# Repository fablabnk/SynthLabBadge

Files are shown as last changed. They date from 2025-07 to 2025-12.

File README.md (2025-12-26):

A light-to-sound badge-synth based on Dylan B's open-hardware Beam Catcher project and coming out of our weekly SynthLab audio hardware meetups at fablab|nk. The badge is designed to be a first-intro to DIY synthesiser building for new visitors. 

Check the [PDF build guide](./BuildGuide/SynthLabBadgeBuildGuide.pdf).

<a href="./BuildGuide/SynthLabBadgeBuildGuide.pdf">
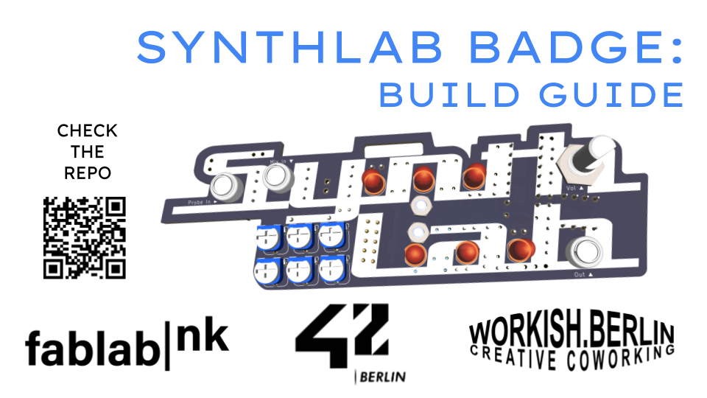
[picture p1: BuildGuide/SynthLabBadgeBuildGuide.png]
    
</a>

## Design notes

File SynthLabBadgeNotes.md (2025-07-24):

SynthLab "Beam Catcher" Badge

# Mouse bites

Graphic import scale: 0.540000

- Badge mounts in panel and can be snapped out
- Traces can't be routed through mouse bites so Eurorack connector must live on badge
- 

1.78

105.156-1.78

# BOM

Thonkiconn input 1 (mix input - will this work?)
Thonkiconn input 2 (sensor)
Thonkiconn output 2 (mono or stereo?)
Master volume pot
6 LEDs
6 trimpots
2 photodiodes
Dual 9v/12v operation (battery, positive rail)
9V battery clip
10 pin IDC connector
Bridgeable reverse voltage protection

# Dimensions
Badge 100 tall
Panel 128.5 tall, 8HP wide 40.64 (or 10HP 50.80)
with screw slots, module name 
 
Logo inside at angle, with mousebites, credits on back

Pot and jack sockets to mount to PCB/Panel and be wired point to point - in which case use guitar pot

Laser cut panel to contain battery and pot (only when used as badge)
- how to mount to PCB - nylon mounts, screws, simpler?
Battery thickness: 17.5 mm
Thonkiconn (base plus pins): 12.5
Pot: don't have datasheet, but must be similar to thonkiconn

How to ensure Eurorack level output? Adjust inverting input and in-the-loop resistor values

height 36mm
wide 100mm
2mm depth fro text and 2mm depth for base badge

clip hole
3mm from top of center

4mm height and 16mm length

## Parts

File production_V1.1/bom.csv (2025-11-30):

Designator | Footprint | Quantity | Value | LCSC Part #
_2, |  | 2
BATTERYMOUNT | 9VBatteryClop | 1 | 9VBatteryClop
BT1 | PinHeader_1x02_P2.54mm_Vertical | 1 | 9V Battery
C1 | C_Axial_L3.8mm_D2.6mm_P7.50mm_Horizontal | 1 | 1uF
C10, C2, C3, C4, C5, C6, C7, C8, C9 | C_Axial_L3.8mm_D2.6mm_P7.50mm_Horizontal | 9 | 100nF
C11 | CP_Radial_D5.0mm_P2.50mm | 1 | 22uF
D2, D3, D4, D5, D6, D7 | LED_D5.0mm | 6 | LED
D8 | D_DO-41_SOD81_P10.16mm_Horizontal | 1 | 5817
J2_2 | Faceplate_Hole_Jack_3.5mm_NoPadNumber | 1 | Probe In
J2 | EighthInch_PJ398SM_Silkscreen_Courtyard_Only | 1 | Probe In
J3_2 | Faceplate_Hole_Jack_3.5mm_NoPadNumber | 1 | Mix_In
J3 | EighthInch_PJ398SM_Silkscreen_Courtyard_Only | 1 | Mix In
J4_2 | EighthInch_PJ398SM_Silkscreen_Courtyard_Only | 1 | Out
J4 | Faceplate_Hole_Jack_3.5mm_NoPadNumber | 1 | Out
J5 | IDC-Header_2x05_P2.54mm_Vertical_Euro_Power_Striped_ThickerText | 1 | Eurorack_Power_10pin_Unshrouded
J6 | PinHeader_1x02_P2.54mm_Vertical | 1 | Mix In
J7 | PinHeader_1x02_P2.54mm_Vertical | 1 | Probe In
J8 | PinHeader_1x03_P2.54mm_Vertical | 1 | Out
J9 | PinHeader_1x02_P2.54mm_Vertical | 1 | Vol Pot
MOUSE-BITE-1MM-SLOT_10, MOUSE-BITE-1MM-SLOT_9, MOUSE-BITE-1MM-SLOT_8, MOUSE-BITE-1MM-SLOT_7, MOUSE-BITE-1MM-SLOT_6, MOUSE-BITE-1MM-SLOT_5, MOUSE-BITE-1MM-SLOT_4, MOUSE-BITE-1MM-SLOT_3, MOUSE-BITE-1MM-SLOT_2, MOUSE-BITE-1MM-SLOT | mouse-bite-1mm-slot | 10 | VAL**
R1, R10, R12, R13, R14, R15, R16, R17, R18, R19, R2, R5, R6, R7, R8, R9 | R_Axial_DIN0207_L6.3mm_D2.5mm_P2.54mm_Vertical | 16 | 1k
R11 | R_Axial_DIN0207_L6.3mm_D2.5mm_P2.54mm_Vertical | 1 | 470
R20, R3 | R_Axial_DIN0207_L6.3mm_D2.5mm_P2.54mm_Vertical | 2 | 100K
R4 | R_Axial_DIN0207_L6.3mm_D2.5mm_P2.54mm_Vertical | 1 | 10k
RV1, RV2, RV4, RV5, RV6, RV7 | Potentiometer_Runtron_RM-065_Vertical | 6 | 1M
RV3_2 | Pot_9mm_DShaft_Silkscreen_Courtyard_Only | 1 | 100K
RV3 | Faceplate_Hole_Jack_3.5mm_NoPadNumber | 1 | 100K
U1 | DIP-8_W7.62mm | 1 | LM358
U2 | DIP-14_W7.62mm | 1 | CD40106BPWR

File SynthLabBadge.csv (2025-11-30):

Reference | Qty | Value | DNP | Exclude from BOM | Exclude from Board | Footprint | Display
BT1 | 1 | 9V Battery |  |  |  | Connector_PinHeader_2.54mm:PinHeader_1x02_P2.54mm_Vertical
C1 | 1 | 1uF |  |  |  | Capacitor_THT:C_Axial_L3.8mm_D2.6mm_P7.50mm_Horizontal
C2,C3,C4,C5,C6,C7,C8,C9,C10 | 9 | 100nF |  |  |  | Capacitor_THT:C_Axial_L3.8mm_D2.6mm_P7.50mm_Horizontal
C11 | 1 | 22uF |  |  |  | Capacitor_THT:CP_Radial_D5.0mm_P2.50mm
D2,D3,D4,D5,D6,D7 | 6 | LED |  |  |  | LED_THT:LED_D5.0mm
D8 | 1 | 5817 |  |  |  | Diode_THT:D_DO-41_SOD81_P10.16mm_Horizontal
J2 | 1 | Probe In |  |  |  | Library:EighthInch_PJ398SM_Silkscreen_Courtyard_Only
J3 | 1 | Mix In |  |  |  | Library:EighthInch_PJ398SM_Silkscreen_Courtyard_Only
J4 | 1 | Out |  |  |  | Library:EighthInch_PJ398SM_Silkscreen_Courtyard_Only
J5 | 1 | Eurorack_Power_10pin_Unshrouded |  |  |  | Library:IDC-Header_2x05_P2.54mm_Vertical_Euro_Power_Striped_ThickerText
J6 | 1 | Mix In |  |  |  | Connector_PinHeader_2.54mm:PinHeader_1x02_P2.54mm_Vertical
J7 | 1 | Probe In |  |  |  | Connector_PinHeader_2.54mm:PinHeader_1x02_P2.54mm_Vertical
J8 | 1 | Out |  |  |  | Connector_PinHeader_2.54mm:PinHeader_1x03_P2.54mm_Vertical
J9 | 1 | Vol Pot |  |  |  | Connector_PinHeader_2.54mm:PinHeader_1x02_P2.54mm_Vertical
R1,R2,R5,R7,R8,R9,R10,R12,R13,R14,R15,R16,R17,R18,R19 | 15 | 1k |  |  |  | Resistor_THT:R_Axial_DIN0207_L6.3mm_D2.5mm_P2.54mm_Vertical
R3,R20 | 2 | 100k |  |  |  | Resistor_THT:R_Axial_DIN0207_L6.3mm_D2.5mm_P2.54mm_Vertical
R4 | 1 | 10k |  |  |  | Resistor_THT:R_Axial_DIN0207_L6.3mm_D2.5mm_P2.54mm_Vertical
R6 | 1 | 1.5k |  |  |  | Resistor_THT:R_Axial_DIN0207_L6.3mm_D2.5mm_P2.54mm_Vertical
R11 | 1 | 470 |  |  |  | Resistor_THT:R_Axial_DIN0207_L6.3mm_D2.5mm_P2.54mm_Vertical
RV1,RV2,RV4,RV5,RV6,RV7 | 6 | 1M |  |  |  | Potentiometer_THT:Potentiometer_Runtron_RM-065_Vertical
RV3 | 1 | 100K |  |  |  | Library:Pot_9mm_DShaft_Silkscreen_Courtyard_Only
U1 | 1 | LM358 |  |  |  | Package_DIP:DIP-8_W7.62mm
U2 | 1 | CD40106BPWR |  |  |  | Package_DIP:DIP-14_W7.62mm | 40106
D1 | 1 | D_Photo | DNP |  | Excluded from board
J1 | 1 | Probe Out | DNP |  | Excluded from board

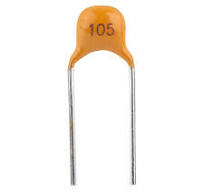
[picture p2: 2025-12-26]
BuildGuide/ComponentImages/download.jpeg

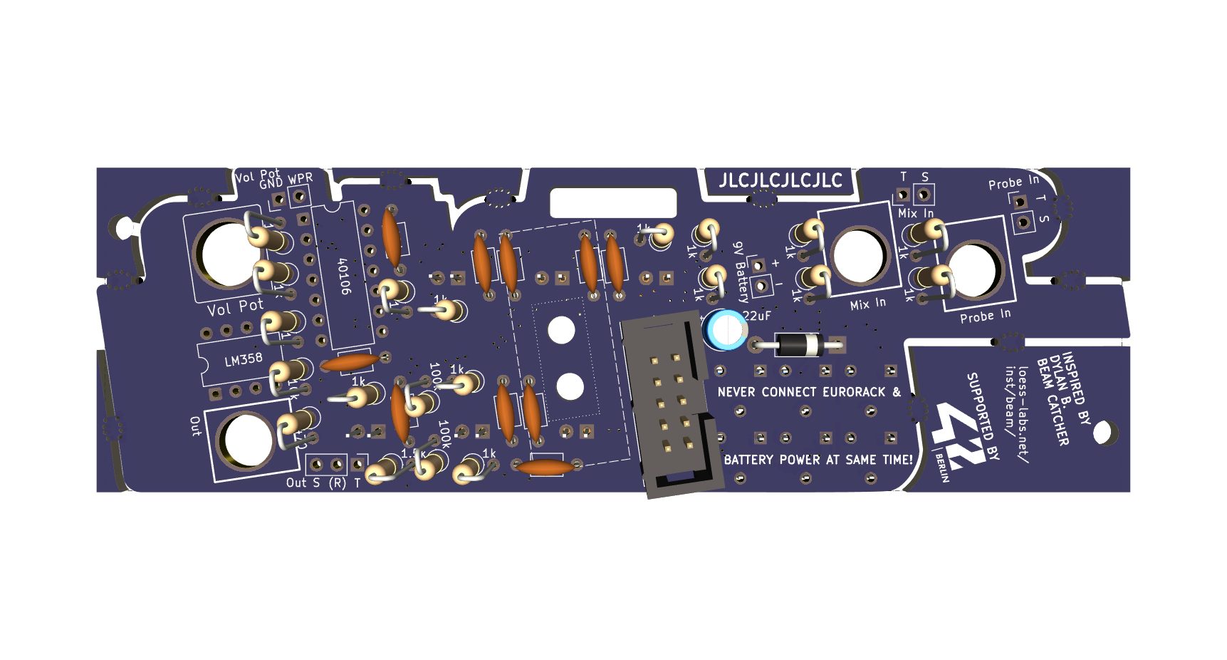
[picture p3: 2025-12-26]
BuildGuide/6-EurorackComponents.png

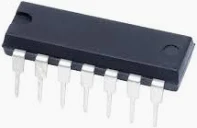
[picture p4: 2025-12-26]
BuildGuide/ComponentImages/CD40106.webp

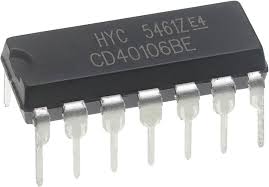
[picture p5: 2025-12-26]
BuildGuide/ComponentImages/CD40106.jpeg

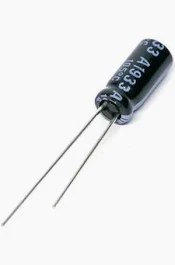
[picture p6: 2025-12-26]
BuildGuide/ComponentImages/shopping.webp

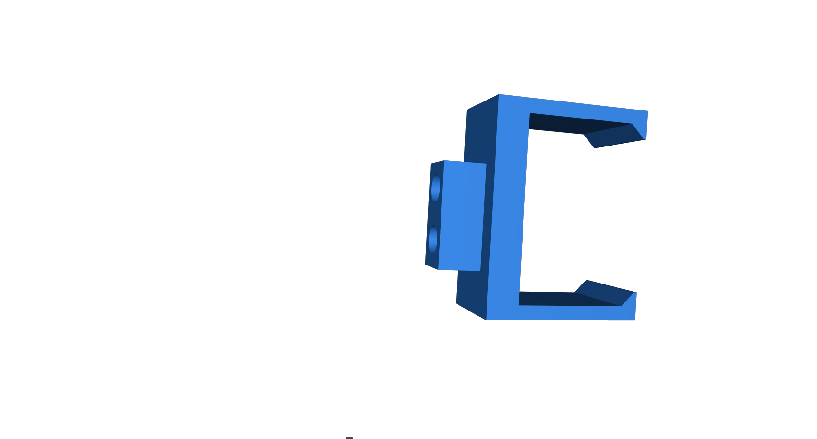
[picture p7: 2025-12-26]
BuildGuide/ComponentImages/9VBatteryMount.png

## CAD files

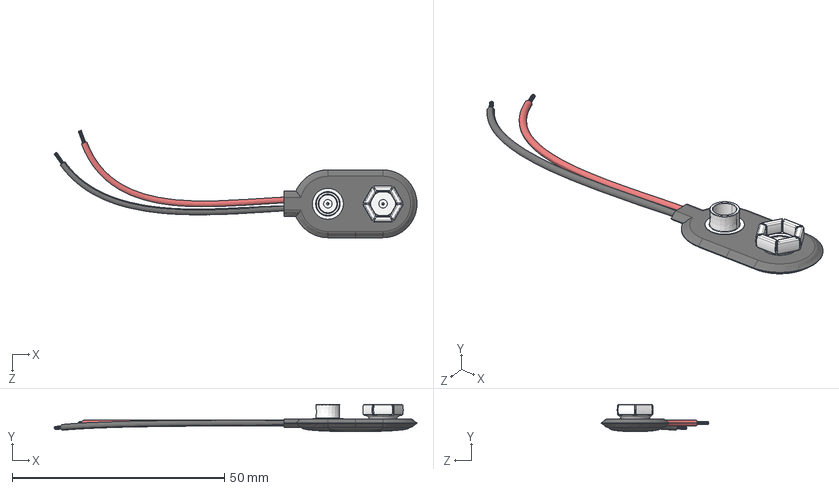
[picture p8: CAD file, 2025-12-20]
3DModels/9V Battery Clip Connector.STEP
85.5 x 6.40 x 25.3 mm

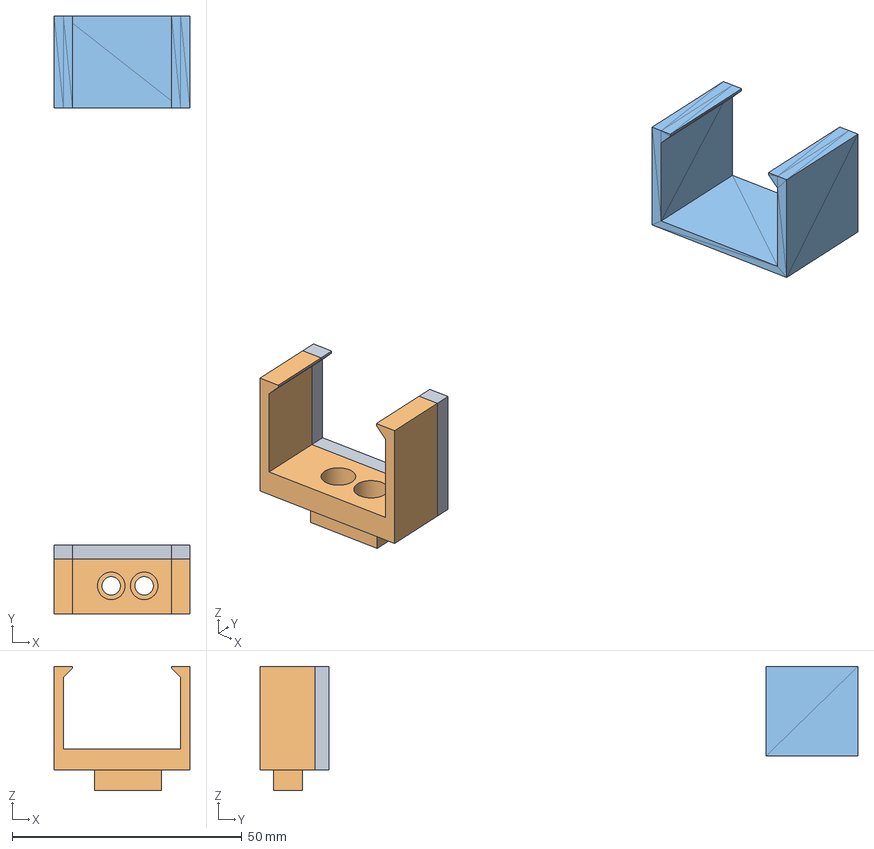
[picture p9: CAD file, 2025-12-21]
9VBatteryClipModel/9VBatteryClipModel.FCStd
29.5 x 130.0 x 27.0 mm
Slice.0
Slice.1
_9vClip_plain001

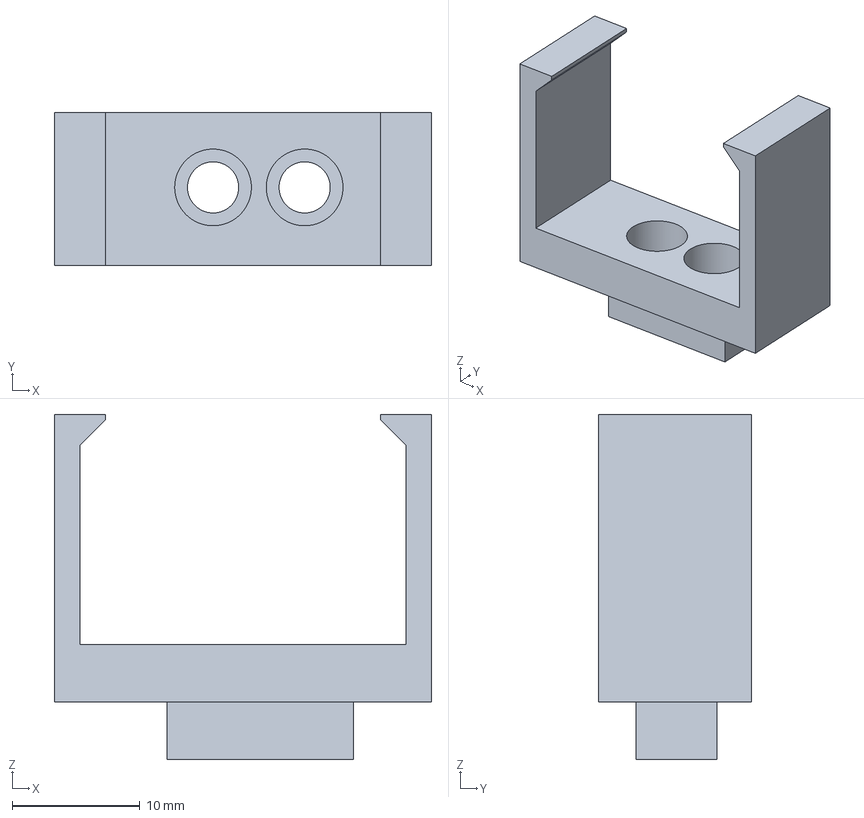
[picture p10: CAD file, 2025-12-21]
9VBatteryClipModel/9VBatteryClipModel-Slice.1.3mf
29.5 x 12.0 x 27.0 mm

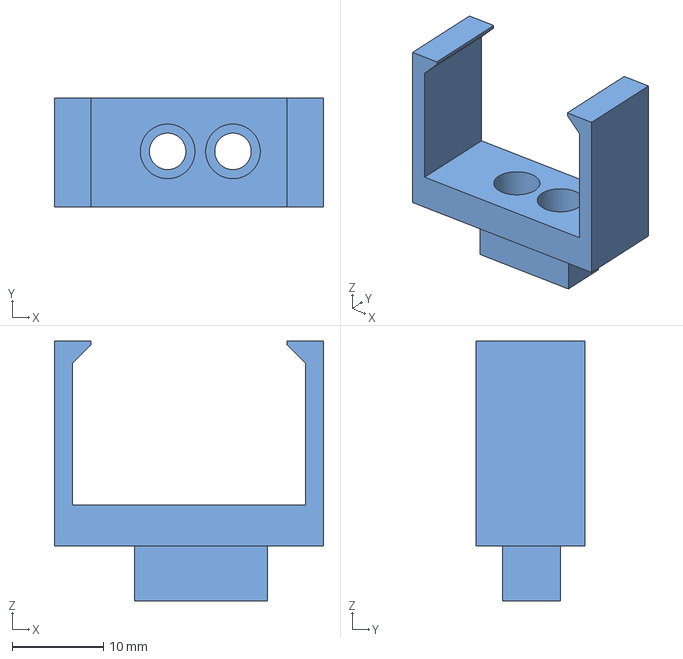
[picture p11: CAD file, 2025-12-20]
3DModels/9VBatteryClip-3DModel.step
29.5 x 12.0 x 28.5 mm

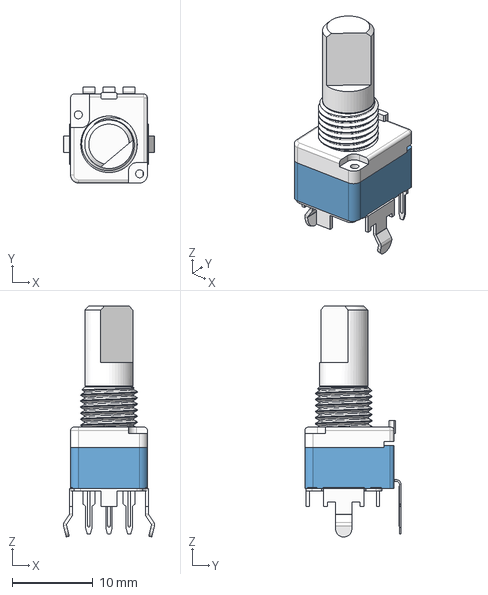
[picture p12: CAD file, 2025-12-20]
3DModels/POT-R-0904N-L-15F.step
11.3 x 11.9 x 28.6 mm

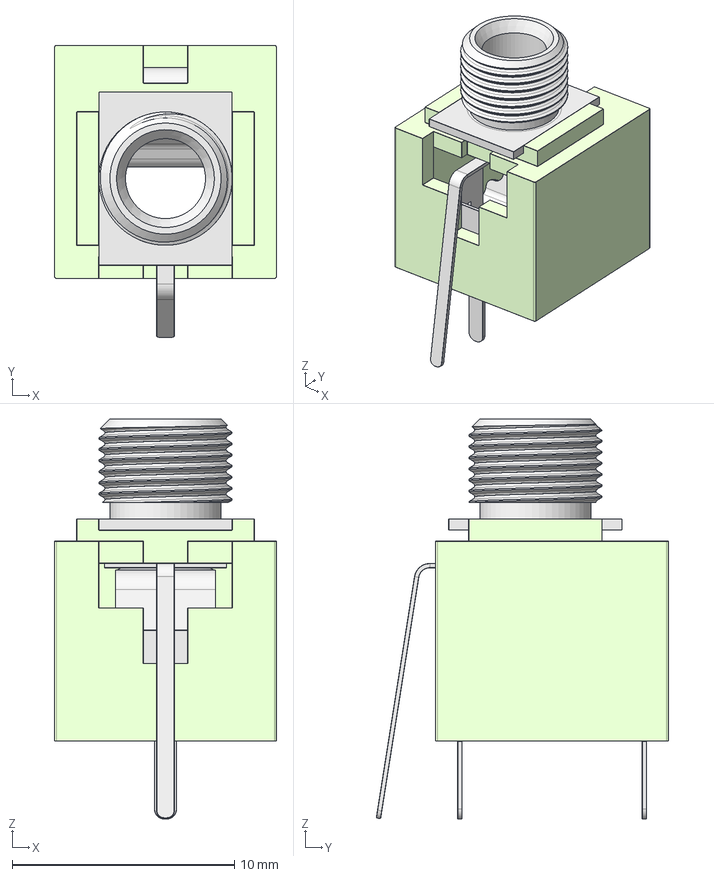
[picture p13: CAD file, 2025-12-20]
3DModels/WPQ-P419GR-Part.step
10.0 x 13.2 x 18.0 mm
Pin 3
Pin 2
Pin 1
Socket

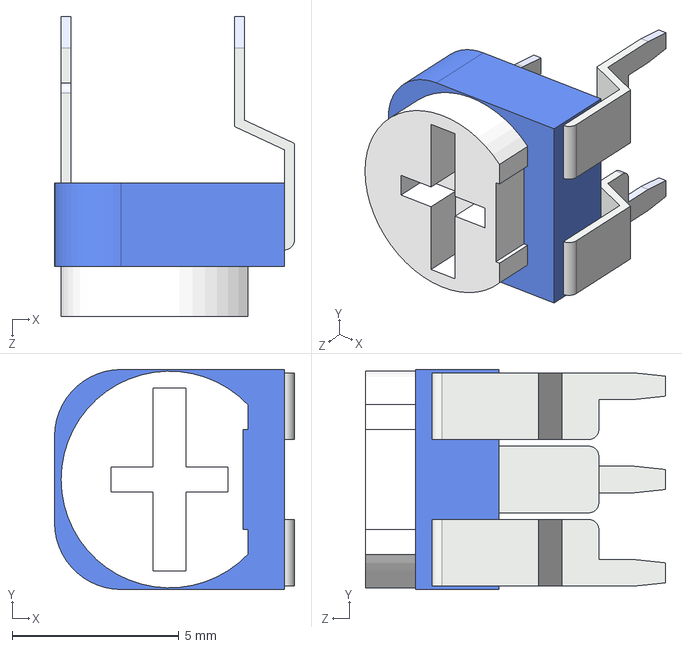
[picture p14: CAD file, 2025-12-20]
3DModels/Potentiometer Blue.STEP
7.20 x 6.60 x 9.00 mm

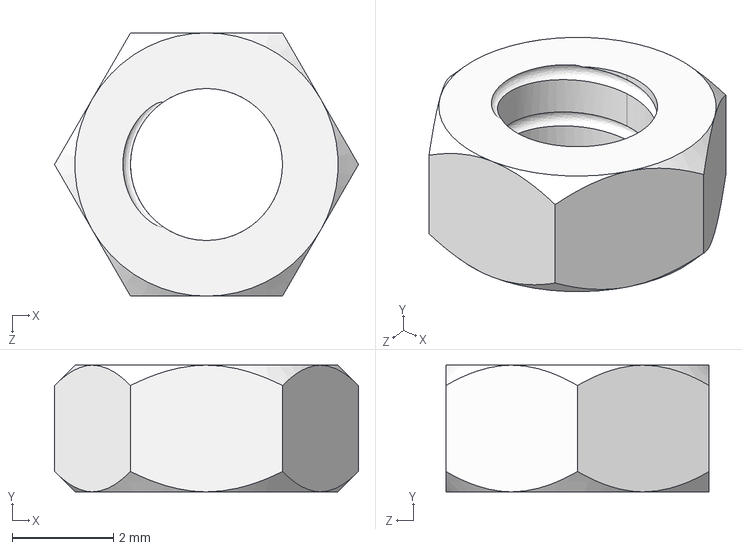
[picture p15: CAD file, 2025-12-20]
3DModels/M3 Nut.STEP
6.00 x 2.50 x 5.20 mm

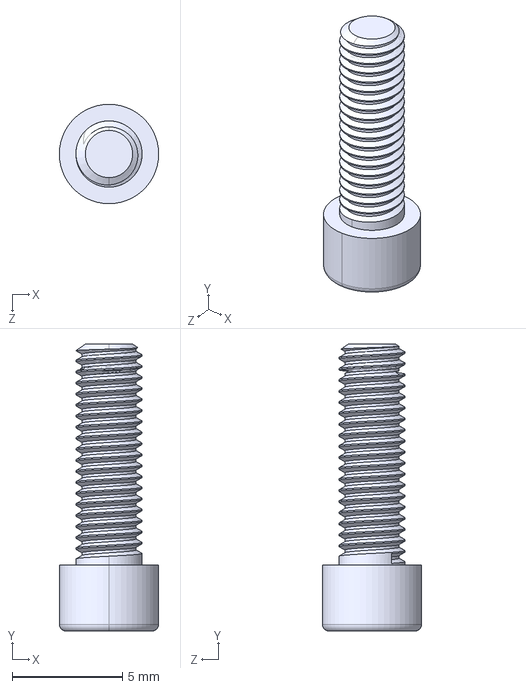
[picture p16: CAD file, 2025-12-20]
3DModels/M3x10.STEP
4.50 x 13.0 x 4.50 mm

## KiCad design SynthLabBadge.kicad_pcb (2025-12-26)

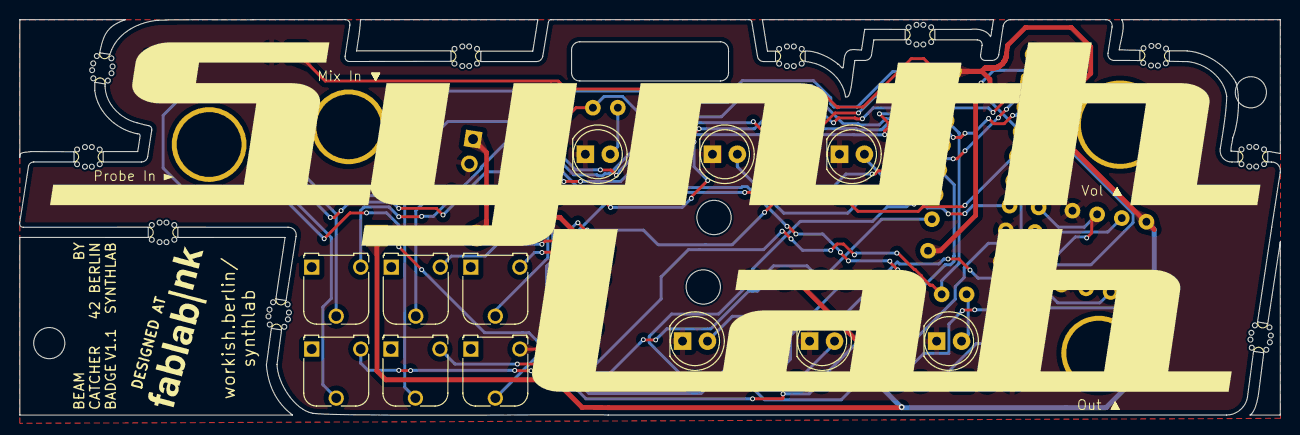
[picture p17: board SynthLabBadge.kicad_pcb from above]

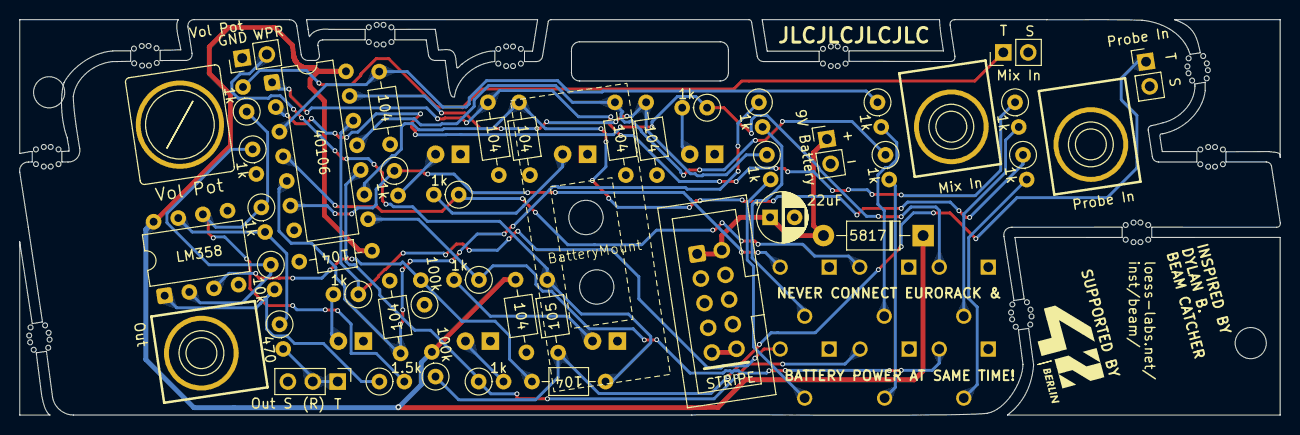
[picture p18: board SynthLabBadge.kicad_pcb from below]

Board: 2 copper layers, 128.5 x 40.3 mm, 71 parts (45 on the bottom side), 37 nets.

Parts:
BT1: 9V Battery; PinHeader_1x02_P2.54mm_Vertical
BatteryMount: 9VBatteryClop
C1: 1uF; C_Axial_L3.8mm_D2.6mm_P7.50mm_Horizontal_Disc3DModel
C2, C3, C4, C5, C6, C7, C8, C9, C10: 100nF; C_Axial_L3.8mm_D2.6mm_P7.50mm_Horizontal_Disc3DModel
C11: 22uF; CP_Radial_D5.0mm_P2.50mm
D2, D3, D4, D5, D6, D7: LED; LED_D5.0mm_Lowered
D8: 5817; D_DO-41_SOD81_P10.16mm_Horizontal
J2: Probe In; Faceplate_Hole_Jack_3.5mm_NoPadNumber
J2#2: Probe In; EighthInch_PJ398SM_Silkscreen_Courtyard_Only
J3: Mix_In; Faceplate_Hole_Jack_3.5mm_NoPadNumber
J3#2: Mix In; EighthInch_PJ398SM_Silkscreen_Courtyard_Only
J4: Out; Faceplate_Hole_Jack_3.5mm_NoPadNumber
J4#2: Out; EighthInch_PJ398SM_Silkscreen_Courtyard_Only
J5: Eurorack_Power_10pin_Unshrouded; IDC-Header_2x05_P2.54mm_Vertical_Euro_Power_Striped_Thicker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
J6: Mix In; PinHeader_1x02_P2.54mm_Vertical
J7: Probe In; PinHeader_1x02_P2.54mm_Vertical
J8: Out; PinHeader_1x03_P2.54mm_Vertical
J9: Vol Pot; PinHeader_1x02_P2.54mm_Vertical
R1, R2, R5, R7, R8, R9, R10, R12, R13, R14, R15, R16, R17, R18, R19: 1k; R_Axial_DIN0207_L6.3mm_D2.5mm_P2.54mm_Vertical
R3, R20: 100k; R_Axial_DIN0207_L6.3mm_D2.5mm_P2.54mm_Vertical
R4: 10k; R_Axial_DIN0207_L6.3mm_D2.5mm_P2.54mm_Vertical
R6: 1.5k; R_Axial_DIN0207_L6.3mm_D2.5mm_P2.54mm_Vertical
R11: 470; R_Axial_DIN0207_L6.3mm_D2.5mm_P2.54mm_Vertical
RV1, RV2, RV4, RV5, RV6, RV7: 1M; Potentiometer_Runtron_RM-065_Vertical_With3DModel
RV3: 100K; Faceplate_Hole_Jack_3.5mm_NoPadNumber
RV3#2: 100K; Pot_9mm_DShaft_Silkscreen_Courtyard_Only
U1: LM358; DIP-8_W7.62mm
U2: CD40106BPWR; DIP-14_W7.62mm
mouse-bite-1mm-slot, mouse-bite-1mm-slot#2, mouse-bite-1mm-slot#3, mouse-bite-1mm-slot#4, mouse-bite-1mm-slot#5, mouse-bite-1mm-slot#6, mouse-bite-1mm-slot#7, mouse-bite-1mm-slot#8, mouse-bite-1mm-slot#9, mouse-bite-1mm-slot#10: VAL**; mouse-bite-1mm-slot

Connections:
GND: BT1.2 (-), C3.2, C4.2, C5.2, C6.2, C7.2, C8.2, C9.2, C10.2, C11.2, D2.1 (K), D3.1 (K), D4.1 (K), D5.1 (K), D6.1 (K), D7.1 (K), J5.3 (GND), J5.4 (GND), J5.5 (GND), J5.6 (GND), J5.7 (GND), J5.8 (GND), J6.S (Pin_2), J7.S (Pin_2), J8.S (Pin_3), J9.1, R3.1, R5.2, U1.4 (V-), U1.5 (+), U2.7 (VSS)
unnamed: BT1.1 (+), C11.1, D8.2 (A), J5.1 (+12V), J5.2 (+12V)
unnamed: D2.2 (A), R14.2
unnamed: D3.2 (A), R17.2
unnamed: D4.2 (A), R15.2
unnamed: D5.2 (A), R18.2
unnamed: D6.2 (A), R16.2
unnamed: D7.2 (A), R19.2
unnamed: J5.9 (-12V), J5.10 (-12V)
unnamed: J6.T (Pin_1), R10.2
unnamed: C1.1, J7.T (Pin_1), R20.1
unnamed: J8.R (Pin_1), J8.T (Pin_2), R11.2
unnamed: C1.2, C2.1, J9.2
unnamed: R1.2, RV1.2
unnamed: R2.2, RV2.2
unnamed: R4.2, R6.1, U1.1
unnamed: R8.2, RV4.2
unnamed: R9.2, RV5.2
unnamed: R7.2, R11.1, U1.7
unnamed: R12.2, RV6.2
unnamed: R13.2, RV7.2
unnamed: C2.2, R3.2, U1.3 (+)
unnamed: R4.1, R5.1, U1.2 (-)
unnamed: R6.2, R7.1, R10.1, U1.6 (-)
unnamed: C4.1, R1.1, U2.1 (I)
unnamed: R14.1, RV1.3, U2.2 (O)
unnamed: C5.1, R2.1, U2.3 (I)
unnamed: R17.1, RV2.3, U2.4 (O)
unnamed: C6.1, R8.1, U2.5 (I)
unnamed: R15.1, RV4.3, U2.6 (O)
unnamed: C7.1, R9.1, U2.9 (I)
unnamed: R18.1, RV5.3, U2.8 (O)
unnamed: C8.1, R12.1, U2.11 (I)
unnamed: R16.1, RV6.3, U2.10 (O)
unnamed: C9.1, R13.1, U2.13 (I)
unnamed: R19.1, RV7.3, U2.12 (O)
VCC: C3.1, C10.1, D8.1 (K), R20.2, U1.8 (V+), U2.14 (VDD)

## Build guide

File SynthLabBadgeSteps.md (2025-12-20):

# Noticed that:

- check if we have enough 1.5k resistors (or other values)
	- in case where output of 9V badge runs into 12V badge, we need more boost
- decide on 1 colour or two (probably 1 - blue)
- check lanyard hole against admins badge
- tunable range is quite extreme

# SynthLab Badge Steps

DONE 1. Fix existing design
	a. LED stage:
	- 100k's to 1k's for 6 LEDS
	- 1k's bridged 
	- Q: is 1k resistor on left or right now? In general follow gerbers
	b. First LM358 stage:
	- VCC -> 100k resistor (add) -> tip input (in parallel)
	- change fbk resistor to 10K
	c. Second LM358 stage:
	- Works fine

DONE 2. Update schematic with above changes

Trimpot doesn't feel logarithmic (it's B100K) - should switch for A100K (test in second design)

DONE 3. A/B test with Eurorack vs battery power

DONE 4. Build a second version to ensure above changes are correct/enough

- DONE: Snap first one out as badge
- Be aware that soldering this will give us 1k resistor on right side, as previously
	- other badge omits these completely I think
	- we should try at least one channel with them on left side (as in new schematic)

DONE 5. Rework PCB design, accounting for:

6. Reorder PCBs

- x 20? two different colours?

7. Reorder AliExpress parts

- Lanyards

8. Build kits

Wait for PCB's/Ali
Test batteries

9. Assemble workshop setup

- effects pedal
- one in Rack 42

# Future

Consider future (self-built) SMT version for cleaner look?

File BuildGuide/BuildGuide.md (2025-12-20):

# BOM

iBom is useful?

CORE

1 x Printed Circuit Board
1 x Lanyard
1 x 9V Battery

FRONT SIDE

BACK SIDE

1 x 9V Battery Clip
1 x 3D printed 9V Battery Mount
2 x M3x8 screws
2 x M3 nuts
1 x 1uF (105) Ceramic Cap
9 x 100nF (104) Ceramic Cap
1 x 22uF Electrolytic Cap
6 x LED 5mm yellow
1 x 1N5817 Diode
1 x PJ-301M 3.5MM Jack Socket (probe, probe in, mix in, out)
1 x 2x5 Pin IDC Eurorack Power Socket
15 x 1k Resistor
2 x 100k Resistor
1 x 10k Resistor
1 x 1.5k Resistor
1 x 470Ohm Resistor
6 x RM-065 1M (105) Trimpot
1 x A100K Potentiometer (surface mount w/ mounting nut)
1 x 8-Pin DIP Socket
1 x LM358 Op-Amp IC
1 x 14 Pin DIP Socket
1 x CD40106 Schmitt Trigger Inverter IC
1 x 5mm photodiode
1 x 3.5mm mono cable

# To Do

Find more spares of
- 1k resistors
- 100k resistors
- 1.5k resistors
Take pliers
104's need more appropriate 3d models (footprint is actually wrong)
Stereo vs Mono Pot

# What's in the bag? Laying out the parts
# Build order

Mistake on board - R6 should read 
Important:
- Add small lengths of wire to kits + battery clips
- Enough 10k spares
- Be sure not to solder resistors in LED holes!
- Don't confuse LEDs and photodiode (latter shows a black square when viewed from top)

BACK: IC sockets and insert ICs (melting risk if done first!)
	- 40106 notch to top
	- LM386 notch to left
BACK: Ceramic capacitors (1 x 105, 8 x 104's)
BACK: Upright resistors
	- from rare to common
1 x 470 Ω: Yellow, Violet, Black, Black, Brown *
1 x 1.5 kΩ: Brown, Green, Black, Brown, Brown *
1 x 10 kΩ: Brown, Black, Black, Red, Brown *
2 x 100 kΩ: Brown, Black, Black, Orange, Brown (1 missing)
15 x 1 kΩ: Brown, Black, Black, Brown, Brown
(check these colour codes)
BACK: 1N5817 Diode
FRONT: 6 x LEDs (not to be confused with photoresistor). Orientation matters!
- insert short leg of LED (cathode, negative) in square pad with flat silkscreening
- insert long leg of LED (anode, positive) in round pad with round silkscreening
- ignore flat and round sides of LED, they're wrong
FRONT: 6 x Trimpots, can only be mounted one way 
BACK: Optional Eurorack components: IDC Header, 22uF cap
BACK: Mount 3 x mono jacks and 1 x pot to back of panel, screwing in at
BACK: Point-to-point wiring
- Vol Pot: 
	- Mount:
		- remove washer and nut
		- mount pot in back of board
		- place washer, then screw on nut from front
		- three pins should point down
	- Solder: wire GND to right pin (?!), WPR to middle pin
- Probe In: T to tip (red), S to sleeve (black)
- Mix In: T to tip (red), S to sleeve (blac)
- Audio Out: T to tip, S to sleeve (mono) and additionally R to (if using stereo connector)
BACK: Attach 3D-printed 9V battery mount.
	- Insert from back and line up holes, ensuring part size matches dotted line
	- Place screws in holes, screw on nuts from front
	- Place 9V battery in the mount, centre it
	- Attach the battery clip to the battery and measure the length of wire needed to go to the 9V Battery holes on the board, leaving a bit extra, cut accordingly
	- Detach the battery clip before soldering. Strip the wire, tin it, insert as follows: 
		- Positive (red) goes to + hole
		- Negative (black) goes to - hole

PROBE: Insert mono 3.5mm jack socket into one end of 3.5mm audio jack cable (helps for stability)
Take photodiode Photodiode (mounted in foam packing)

TEST: Attach 9V battery. Come to audio testing station
BREAKOUT: Use small pliers to break off if using as a badge
LANYARD: attach and wear with pride

# Components with Orientation

Diode
Electrolytic Cap

# Eurorack Components (optional)

# Wiring

Tip vs Sleeve

# Probe Building

Solder photodiode to thonkiconn
- negative (flat side) to sleeve
- positive (round side) to tip

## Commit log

2025-07-24 finalising silkscreening
    [SynthLabBadge.kicad_pcb, SynthLabBadge.kicad_sch]
2025-07-24 final check before production
    [SynthLabBadge.kicad_pcb, bom.csv, designators.csv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]
2025-07-24 committing before sending to production
    [SynthLabBadge.kicad_pcb, SynthLabBadge.kicad_sch, bom.csv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]
2025-11-29 commiting before trying to move components from bottom of board
    [9VBatteryClipModel.FCStd, SynthLabBadge.kicad_pcb, SynthLabBadge.kicad_sch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]
2025-11-30 V1.1 ready for production
    [9VBatteryClipModel-Body.3mf, 9VBatteryClipModel.FCStd, SynthLabBadge.kicad_pcb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]
2025-11-30 V1.1 ready for production - barring lanyard hole check
2025-12-20 All 3D models added and positioned - ready to create build guide
    [9VBatteryClip-3DModel.step, POT-R-0904N-L-15F.step, Potentiometer Blue.STEP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]
2025-12-20 increased height of battery clip
    [9VBatteryClip-3DModel.step, 9VBatteryClipModel-Body.3mf, 9VBatteryClipModel-Slice.1.3mf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]
2025-12-20 Pushing before propagating mono jack screws to other footprints
    [M3 Nut.STEP, M3x10.STEP, SynthLabBadge.kicad_pcb]
2025-12-20 Footprints updated - screws and nuts now added to 3D models
    [SynthLabBadge.kicad_pcb]
2025-12-20 added battery clip and build guide screenshots
    [9V Battery Clip Connector.STEP, SynthLabBadge.kicad_pcb]
2025-12-21 Committing before creating temp broken-out version of board for build guide
    [SynthLabBadge.kicad_pcb]
2025-12-26 Added build guide for 39C3 workshop
    [SynthLabBadge.kicad_pcb]
